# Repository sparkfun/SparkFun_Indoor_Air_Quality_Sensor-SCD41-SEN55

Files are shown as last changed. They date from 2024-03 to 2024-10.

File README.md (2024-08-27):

SparkFun Indoor Air Quality Sensor - SCD41 SEN55 (Qwiic)
========================================

SparkFun Indoor Air Quality Sensor - SCD41 SEN55 (https://www.sparkfun.com/products/25200)

[*SparkFun Indoor Air Quality Sensor - SCD41 SEN55 (SEN-25200)*](https://www.sparkfun.com/products/25200)

The SparkFun Indoor Air Quality Sensor - SCD41 SEN55 (Qwiic) combines two excellent indoor air quality sensors in the SCD41 and SEN55 from Sensirion<sup>&trade;</sup> to provide a comprehensive indoor air quality sensor that measures CO<sub>2</sub>, Volatile Organic Compounds (VOCs), particulate matter (PM1.0, 2.5, 4, and 10) along with temperature and relative humidity. The board includes a pair of Qwiic connectors as well as a 0.1"-spaced through-hole header for I<sup>2</sup>C connections as well as power inputs.

Repository Contents
-------------------

* **/docs** - Markdown files for Hookup Guide
* **/Documents** - Datasheets, additional product information
* **/Firmware** - Example code 
* **/Hardware** - Eagle design files (.brd, .sch)

Documentation
--------------
* **[SparkFun SCD4x Library](https://github.com/sparkfun/SparkFun_SCD4x_Arduino_Library)** - Arduino library for SDC4x sensor boards.
* **[Sensirion Arduino Core Library](https://github.com/Sensirion/arduino-core)** - Arduino core library for Sensirion sensors.
* **[Sensirion SEN5x Library](https://github.com/Sensirion/arduino-i2c-sen5x)** - Arduino library for the Sensirion SEN55.
* **[Hookup Guide](https://sparkfun.github.io/SparkFun_Indoor_Air_Quality_Sensor-SCD41-SEN55)** - Basic hookup guide for the SparkFun Indoor Air Quality Sensor - SCD41 SEN55 (Qwiic).

Product Versions
----------------
* [SEN-25200](https://www.sparkfun.com/products/25200) - Initial product release.

License Information
-------------------

This product is _**open source**_! 

Please review the LICENSE.md file for license information. 

If you have any questions or concerns on licensing, please contact technical support on our [SparkFun forums](https://forum.sparkfun.com/viewforum.php?f=152).

Distributed as-is; no warranty is given.

- Your friends at SparkFun.

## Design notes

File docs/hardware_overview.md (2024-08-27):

---
icon: material/cog
---

Let's take a closer look at the pair of sensors along with other hardware present on this Qwiic sensor breakout.

## SEN55 Particle, VOC, Humidity, and Temperature Sensor

The SEN55 Particle and VOC sensor module measures particulate matter and volatile organic compounds (VOCs) along with humidity and temperature. The SEN55 is designed with the idea to be a simple plug-and-play solution and includes all sensors, processors, power control, and fan inside a compact housing all with a single, calibrated, digital signal output communicating over I<sup>2</sup>C making it perfect to integrate into this Qwiic combination breakout.

<figure markdown>
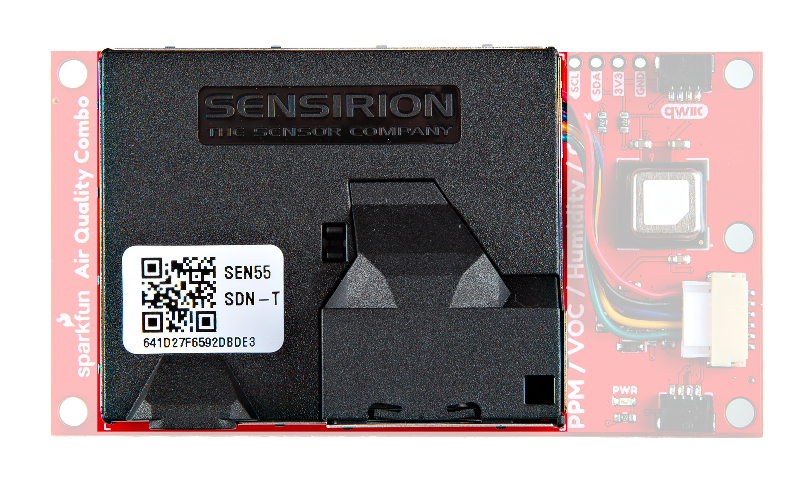
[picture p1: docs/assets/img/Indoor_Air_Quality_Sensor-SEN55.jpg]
Photo highlighting SEN55

</figure>

The SEN55 reports measurments of particulate matter, VOC index, NO<sub>x</sub> indect, temperature, and relative humidity every second. The sensor measures particulates of the following size specifications: PM1, PM2.5, PM4, and PM10 from a concentration of 0 to 1,000 &micro;g/m<sup>3</sup>. It also senses both VOC and NO<sup>x</sup> indexes from 1 to 500 index points. Lastly, it measures temperature from 15 to 30&deg;C and relative humidity from 30 to 70%RH. It offers a robust set of control registers to take and report measurements as well as check the status of the module and its components. The table below outlines some of the sensing parameters for the SEN55. Refer to the [datasheet](./assets/component_documentation/Sensirion_Datasheet_Environmental_Node_SEN5x.pdf) for a complete overview.

<table>
    <tr>
        <th>Parameter</th>
        <th>Units</th>
        <th>Min</th>
        <th>Typ</th>
        <th>Max</th>
        <th>Conditions/Notes</th>
    </tr>
    <tr>
        <td>Mass concentration range</td>
        <td>&micro;g/m<sup>3</sup></td>
        <td>-</td>
        <td>0</td>
        <td>-</td>
        <td>1,000</td>
        <td>-</td>        
    </tr>
    <tr>
        <td>PM1.0 Mass concentration size</td>
        <td>&micro;g</td>
        <td>0.3</td>
        <td>-</td>
        <td>1.0</td>
        <td>-</td>
    </tr>
    <tr>
        <td>PM2.5 Mass concentration size</td>
        <td>&micro;g</td>
        <td>0.3</td>
        <td>-</td>
        <td>2.5</td>
        <td>-</td>
    </tr>
    <tr>
        <td>PM4 Mass concentration size</td>
        <td>&micro;g</td>
        <td>0.3</td>
        <td>-</td>
        <td>4.0</td>
        <td>-</td>
    </tr>
    <tr>
        <td>PM10 Mass concentration size</td>
        <td>&micro;g</td>
        <td>0.3</td>
        <td>-</td>
        <td>10.0</td>
        <td>-</td>
    </tr>
    <tr>
        <td>Temperature accuracy (Typ.)</td>
        <td>&deg;C</td>
        <td>-</td>
        <td>&plusmn;0.45</td>
        <td>-</td>
        <td>@ 15-30 &deg;C, 50 %RH</td>
    </tr>
    <tr>
        <td>Temperature repeatability</td>
        <td>&deg;C</td>
        <td>-</td>
        <td>0.1</td>
        <td>-</td>
        <td>@25&deg;C, 50 %RH</td>
    </tr>
    <tr>
        <td>Relative humidity accuracy (Typ.)</td>
        <td>%RH</td>
        <td>-</td>
        <td>&plusmn;4.5</td>
        <td>-</td>
        <td>@25&deg;C, 30-70 %RH</td>
    </tr>
    <tr>
        <td>Relative humidity repeatability</td>
        <td>%RH</td>
        <td>-</td>
        <td>&plusmn;1</td>
        <td>-</td>
        <td>@25&deg;C, 50 %RH</td>
    </tr>
    <tr>
        <td>VOC Index output</td>
        <td>VOC Index points</td>
        <td>1</td>
        <td>-</td>
        <td>500</td>
        <td>-</td>
    </tr>
    <tr>
        <td>VOC Index repeatability</td>
        <td>VOC Index points</td>
        <td>-</td>
        <td><&plusmn;5</td>
        <td>-</td>
        <td>-</td>
    </tr>
    <tr>
        <td>NO<sub>x</sub> Index output</td>
        <td>NO<sub>x</sub> Index points</td>
        <td>1</td>
        <td>-</td>
        <td>500</td>
        <td>-</td>
    </tr>
    <tr>
        <td>NO<sub>x</sub> Index repeatability</td>
        <td>NO<sub>x</sub> Index points</td>
        <td>-</td>
        <td><&plusmn;10</td>
        <td>-</td>
        <td>-</td>
    </tr>
</table>

### SEN55 Power

The SEN55 accepts a supply voltage between <b>4.5V</b> to <b>5.5V</b> with a typical voltage of <b>5V</b> with a peak current draw of <b>110mA@5V</b>. The SparkFun Indoor Air Quality Sensor uses an on-board buck/boost circuit to boost the <b>3.3V</b> from a Qwiic connector or to the <b>3.3V</b> PTH pin to <b>5V</b>.

## SCD41 CO<sub>2</sub> Humidity and Temperature Sensor

The SCD41 CO<sub>2</sub> sensor uses Sensirion's PASense<sup>&trade;</sup>, a photoacoustic measurement system, to accurately measure CO<sub>2</sub> concentration using a combination of a narrow band of IR light and a microphone. The sensor also has a built-in humidity and temperatuer sensor using Sensirion's CMOSens<sup>&trade;</sup> technology to provide environmental data and compensate for environmental conditions in CO<sub>2</sub> measurement. For a detailed overview of the SCD41 sensor, refer to the [datasheet](./assets/component_documentation/Sensirion_CO2_Sensors_SCD4x_Datasheet.pdf).

<figure markdown>
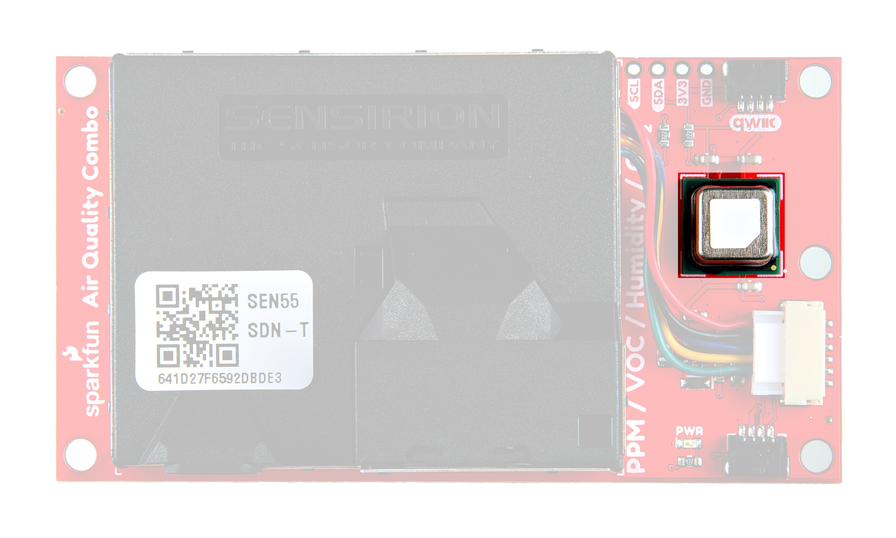
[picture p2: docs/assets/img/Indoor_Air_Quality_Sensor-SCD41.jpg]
Photo highlighting SCD41

</figure>

Now you may be curious as to just what photoacoustic measuring actually is. Photoacoustic measuring uses light (photo) and sound/vibrations (acoustic) in tandem to measure the the photoacoustic effect when energy is absorbed by particles (in the case of these sensors, CO<sub>2</sub> molecules). The SCD41 has an IR emitter with a filter to shine a specific IR light into the sensing area. CO<sub>2</sub> molecules inside the sensing area absorb energy from the emitted IR light and vibrate. The microphone inside the sensing area picks up this acoustic vibration and then this data is processed to report CO<sub>2</sub> concentration. This is just a quick and basic explanation of the photoacoustic process used in this sensor. For detailed information on Sensirion's PASens and CMOSens technology, refer to their [technology page](https://sensirion.com/products/technology).

<table>
    <tr>
        <th>Parameter</th>
        <th>Units</th>
        <th>Min</th>
        <th>Typ</th>
        <th>Max</th>
        <th>Notes</th>
    </tr>
    <tr>
        <td>CO<sub>2</sub> Output Range</td>
        <td>ppm</td>
        <td>0</td>
        <td>-</td>
        <td>40,000</td>
        <td></td>
    </tr>
    <tr>
        <td>CO<sub>2</sub> Measurement Accuracy</td>
        <td>ppm</td>
        <td>-</td>
        <td>&plusmn;(40 + 5%)</td>
        <td>-</td>
        <td>-</td>
    </tr>
    <tr>
        <td>Humidity Range</td>
        <td>%RH</td>
        <td>0</td>
        <td>-</td>
        <td>100</td>
        <td></td>
    </tr>
    <tr>
        <td rowspan="2" style="vertical align middle">Humidity Accuracy</td>
        <td rowspan="2" style="vertical align middle">%RH</td>
        <td>-</td>
        <td>&plusmn;6</td>
        <td>-</td>
        <td>15&deg;C - 35&deg;C, 20%RH - 65%RH</td>
    </tr>
    <tr>
        <td>-</td>
        <td>&plusmn;9</td>
        <td>-</td>
        <td>-10&deg;C - 60 &deg;C, 0%RH - 100%RH</td>
    </tr>
    <tr>
        <td>Temperature Range</td>
        <td>&deg;C</td>
        <td>-10</td>
        <td>-</td>
        <td>60</td>
        <td></td>
    </tr>
    <tr>
        <td rowspan="2" style="vertical align middle">Temperature Accuracy</td>
        <td rowspan="2" style="vertical align middle">&deg;C</td>
        <td>-</td>
        <td>&plusmn;0.8</td>
        <td>-</td>
        <td>15&deg;C - 35&deg;C</td>
    </tr>
    <tr>
        <td>-</td>
        <td>&plusmn;1.5</td>
        <td>-</td>
        <td>-10&deg;C - 60&deg;C</td>
    </tr>
</table>

## Qwiic & I<sup>2</sup>C Interface

The Indoor Air Quality Sensor operates over I<sup>2</sup>C using either the two Qwiic connectors or the 0.1"-spaced plated through-hole (PTH) header. Power for the board is supplied over either of these options as well.

<figure markdown>
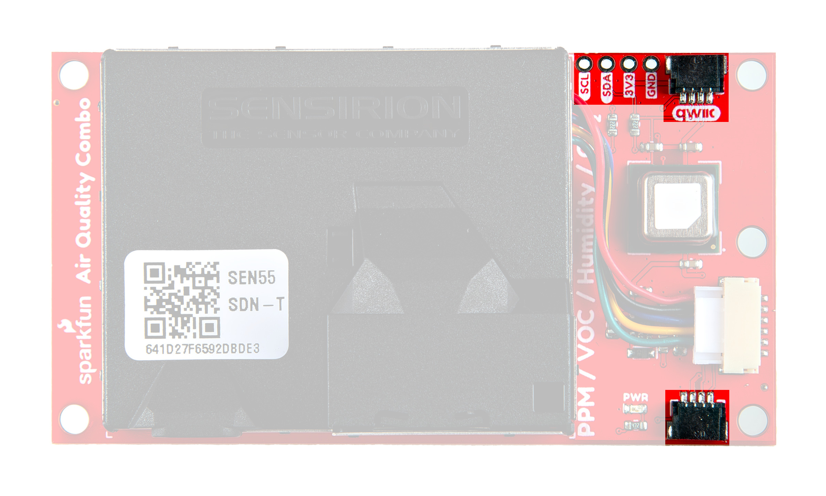
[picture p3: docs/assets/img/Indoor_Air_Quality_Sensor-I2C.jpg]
Photo highlighting Qwiic connectors & I2C header.

</figure>

## Power LED

There is just one red LED on the board to indicate power. By default, it is always powered whenever <b>3.3V</b> is present though users can disable it by adjusting the solder jumper covered in the next section.

<figure markdown>
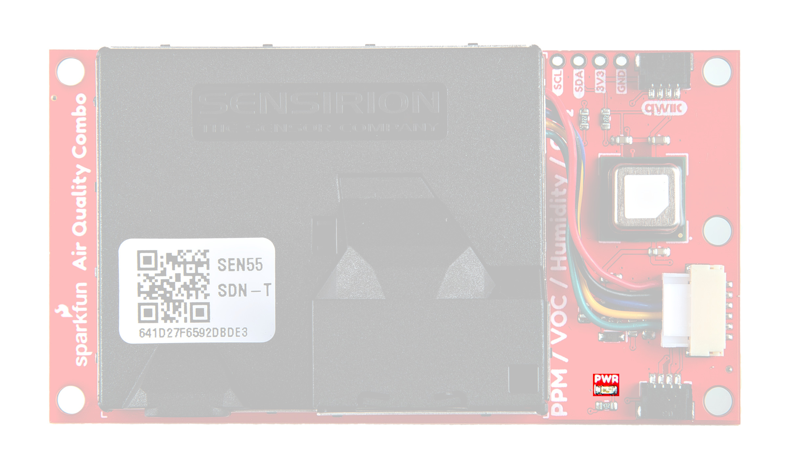
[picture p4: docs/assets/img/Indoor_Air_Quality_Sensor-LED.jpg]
Photo highlighting Power LED.

</figure>

## Solder Jumpers

The board has two solder jumpers labeled <b>PWR</b> and <b>I2C</b>. The <b>PWR</b> jumper completes the power LED circuit and is CLOSED by default. Open the jumper to disable the power LED. The <b>I2C</b> jumper pulls the I<sup>2</sup>C SDA and SCL lines to <b>3.3V</b> via a pair of <b>2.2k</b>&ohm; resistors. This three way jumper is completely closed by default. Open it completely to disable the pullup resistors.

<figure markdown>
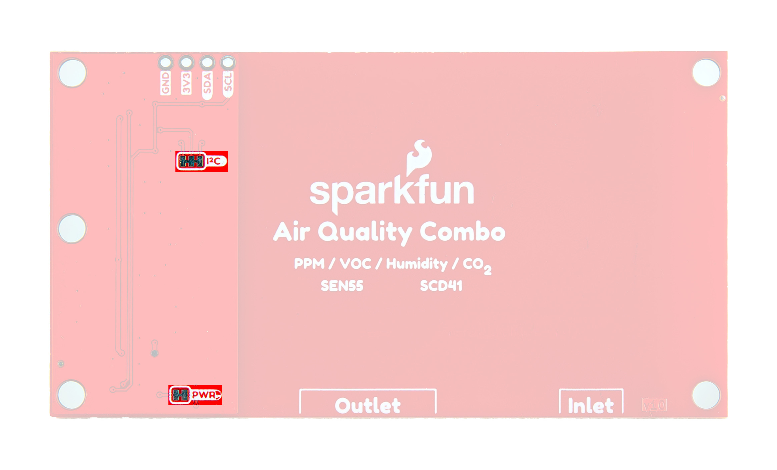
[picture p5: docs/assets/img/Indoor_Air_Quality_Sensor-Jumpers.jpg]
Photo highlighting solder jumpers.

</figure>

## Board Dimensions

This Qwiic breakout runs a bit larger than standard Qwiic breakouts to fit the SEN55 and measures 3.25" x 1.75" (82.55mm x 44.45mm) and has four mounting holes that fit a [4-40 screw](https://www.sparkfun.com/products/10453). The SEN55 is a bit of an odd shape to fit everything in the housing but it measures 0.878" (22.3mm) at it's tallest and it's footprint is 2.06" x  1.70" (52.3 mm x 43.3 mm). For detailed measurements of the entire sensor package, refer to the [SEN55 datasheet](./assets/component_documentation/Sensirion_Datasheet_Environmental_Node_SEN5x.pdf).

<figure markdown>
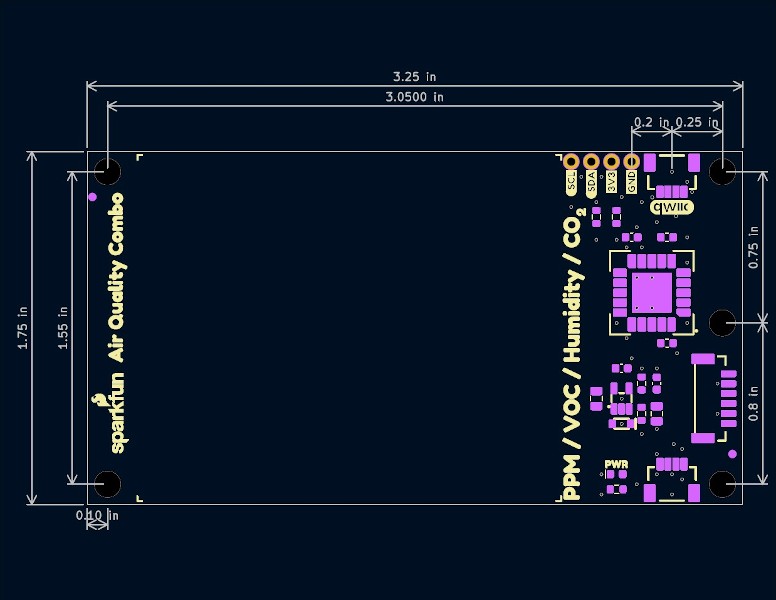
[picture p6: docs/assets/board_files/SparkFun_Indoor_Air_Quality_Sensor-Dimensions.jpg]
Board dimensions

</figure markdown>

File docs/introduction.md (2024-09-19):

---
icon: material/book-open-page-variant
---

<div class="grid cards desc" markdown>

-    <a href="https://www.sparkfun.com/products/25200">
    **SparkFun Indoor Air Quality Combo Sensor - SCD41, SEN55 (Qwiic)**<br>
    **SKU:** SEN-25200

    ---

    <figre markdown>
    Product Thumbnail
    </figure></a>

    <center>
    <article class="video_desc">
    <iframe src="https://www.youtube.com/embed/Cn1trZE5GPI?si=KZZngeRyTVlIOeQ6" title="Product Showcase: SparkFun Indoor Air Quality Combo Sensor - SCD41, SEN55 (Qwiic)" frameborder="0" allow="accelerometer; autoplay; clipboard-write;encrypted-media; gyroscope; picture-in-picture" allowfullscreen></iframe>
    </article>
    </center>

-    The SparkFun Indoor Air Quality Combo Sensor - SCD41 SEN55 (Qwiic) combines two excellent indoor air quality sensors in the SCD41 and SEN55 from Sensirion<sup>&trade;</sup> to provide a comprehensive indoor air quality sensor that measures CO<sub>2</sub>, Volatile Organic Compounds (VOCs), particulate matter (PM1.0, 2.5, 4, and 10) along with temperature and relative humidity.<br>
The SparkFun Qwiic Indoor Air Quality Combo Sensor takes care of all the power requirements of the SEN55 and SCD41 with onboard DC voltage conversion, allowing a simple, single Qwiic connection for power and communication.

    <center>
    [Purchase from SparkFun :fontawesome-solid-cart-plus:{ .heart }](https://www.sparkfun.com/products/25200){ .md-button .md-button--primary }
    </center>

</div>

## Required Materials

To follow along with this guide you will need a microcontroller to communicate with the Indoor Air Quality Combo Board. Below are a few options that come Qwiic-enabled out of the box:

<div class="grid cards" markdown>

-   <a href="https://www.sparkfun.com/products/20168">

    <figure markdown>
    SparkFun Thing Plus - ESP32 WROOM (USB-C)
    </figure>
    </a>
    ---
    <a href="https://www.sparkfun.com/products/20168">
    **SparkFun Thing Plus - ESP32 WROOM (USB-C)**<br>
    DEV-20168
    </a>

-   <a href="https://www.sparkfun.com/products/22925">

    <figure markdown>
    SparkFun Qwiic Pocket Development Board - ESP32-C6
    </figure>
    </a>
    ---
    <a href="https://www.sparkfun.com/products/22925">**SparkFun Qwiic Pocket Development Board - ESP32-C6**<br>
    DEV-22925
    </a>

-   <a href="https://www.sparkfun.com/products/15574">
    
    <figure markdown>
    SparkFun Thing Plus - Artemis
    </figure>
    </a>
    ---
    <a href="https://www.sparkfun.com/products/15574">
    **SparkFun Thing Plus - Artemis**<br>
    DEV-18158
    </a>

-   <a href="https://www.sparkfun.com/products/18158">
    
    <figure markdown>
    SparkFun RedBoard Plus
    </figure>
    </a>
    ---
    <a href="https://www.sparkfun.com/products/18158">
    **SparkFun RedBoard Plus**<br>
    DEV-18158
    </a>

</div>

If your chosen microcontroller is not already Qwiic-enabled, you can add that functionality with one or more of the following items:

<div class="grid cards" markdown>

-   <a href="https://www.sparkfun.com/products/15081">

    <figure markdown>
    SparkFun Qwiic Cable Kit
    </figure>
    </a>
    ---
    <a href="https://www.sparkfun.com/products/15081">
    **SparkFun Qwiic Cable Kit**<br>
    KIT-15081
    </a>

-   <a href="https://www.sparkfun.com/products/14495">
    
    <figure markdown>
    SparkFun Qwiic Adapter
    </figure>
    </a>
    ---
    <a href="https://www.sparkfun.com/products/14495">
    **SparkFun Qwiic Adapter**<br>
    DEV-14495
    </a>

-   <a href="https://www.sparkfun.com/products/14352">
    
    <figure markdown>
    SparkFun Qwiic Shield for Arduino
    </figure>
    </a>
    ---
    <a href="https://www.sparkfun.com/products/14352">
    **SparkFun Qwiic Shield for Arduino**<br>
    DEV-14352
    </a>

-   <a href="https://www.sparkfun.com/products/16790">

    <figure markdown>
    SparkFun Qwiic Shield for Thing Plus
    </figure>
    </a>
    ---
    <a href="https://www.sparkfun.com/products/16790">
    **SparkFun Qwiic Shield for Thing Plus**<br>
    DEV-16790
    </a>
</div>

You will also need at least one Qwiic cable to connect the air quality sensor board to your microcontroller:

<div class="grid cards" markdown>

-   <a href="https://www.sparkfun.com/products/17259">

    <figure markdown>
    Flexible Qwiic Cable - 100mm)
    </figure>
    </a>
    ---
    <a href="https://www.sparkfun.com/products/17259">
    **Flexible Qwiic Cable - 100mm**<br>
    PRT-17259
    </a>

-   <a href="https://www.sparkfun.com/products/17260">
    
    <figure markdown>
    Qwiic Cable - 50mm
    </figure>
    </a>
    ---
    <a href="https://www.sparkfun.com/products/17260">
    **Flexible Qwiic Cable - 50mm**<br>
    PRT-17260
    </a>

-   <a href="https://www.sparkfun.com/products/17257">
    
    <figure markdown>
    Flexible Qwiic Cable - 500mm
    </figure>
    </a>
    ---
    <a href="https://www.sparkfun.com/products/17257">
    **Flexible Qwiic Cable - 500mm**<br>
    PRT-17257
    </a>

-   <a href="https://www.sparkfun.com/products/17261">

    <figure markdown>
    Flexible Qwiic Cable - Female Jumper (4-pin)
    </figure>
    </a>
    ---
    <a href="https://www.sparkfun.com/products/17261">**Flexible Qwiic Cable - Female Jumper (4-pin)**<br>
    CAB-17261
    </a>
</div>

## Optional Materials

If you prefer a soldered connection or want to modify the solder jumpers on this board, you may need some of the products listed below:

<div class="grid cards" markdown align="center">

-   <a href="https://www.sparkfun.com/products/24063">
    
    <figure markdown>
    PINECIL Soldering Iron Kit
    </figure>
    </a>
    ---
    <a href="https://www.sparkfun.com/products/24063">
    **PINECIL Soldering Iron Kit**<br>
    TOL-24063
    </a>

-   <a href="https://www.sparkfun.com/products/116">

    <figure markdown>
    Break Away Headers - Straight)
    </figure>
    </a>
    ---
    <a href="https://www.sparkfun.com/products/116">
    **Break Away Headers - Straight**<br>
    PRT-00116
    </a>

-   <a href="https://www.sparkfun.com/products/9200">
    
    <figure markdown>
    Hobby Knife
    </figure>
    </a>
    ---
    <a href="https://www.sparkfun.com/products/9200">
    **Hobby Knife**<br>
    TOL-09200
    </a>

-   <a href="https://www.sparkfun.com/products/14579">

    <figure markdown>
    Chip Quik No-Clean Flux Pen - 10mL
    </figure>
    </a>
    ---
    <a href="https://www.sparkfun.com/products/14579">**Chip Quik No-Clean Flux Pen - 10mL**<br>
    CAB-14579
    </a>
</div>

## Suggested Reading

We designed this board for easy integration into SparkFun's Qwiic connect system.  Click on the banner below to learn more about the [SparkFun Qwiic Connect System](https://www.sparkfun.com/qwiic).

<div style="text-align: center">
<table>
  <tr>
   <td>
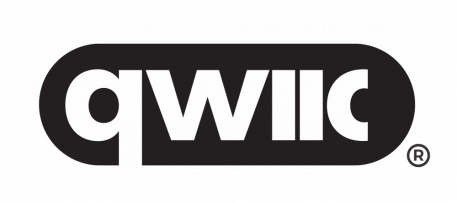
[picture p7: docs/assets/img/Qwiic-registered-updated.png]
Qwiic Connect System Click to learn more about the Qwiic Connect System!
   <div style="text-align: center"></div>
   </td>
  </tr>
  <tr>
    <td><div style="text-align: center"><i><a href="https://www.sparkfun.com/qwiic">Qwiic Connect System</a></i></div></td>
  </tr>
</table>
</div>

Before getting started with this Hookup Guide, you may want to read through the tutorials below if you are not familiar with the concepts covered in them or want a refresher. If you are using either of the Qwiic Shields linked above, we recommend reading through their respective Hookup Guides before continuing with this tutorial:

<div class="grid cards hide col-4" markdown align="center">

-   <a href="https://learn.sparkfun.com/tutorials/8">
    <figure markdown>
    Serial Communication
    </figure>
    </a>
    <a href="https://learn.sparkfun.com/tutorials/8">**Serial Communication**
    </a>

-   <a href="https://learn.sparkfun.com/tutorials/82">
    <figure markdown>
    I2C
    </figure>
    </a>
    <a href="https://learn.sparkfun.com/tutorials/82">**I2C**
    </a>

-   <a href="https://learn.sparkfun.com/tutorials/62">
    <figure markdown>
    Logic Levels
    </figure>
    </a>
    <a href="https://learn.sparkfun.com/tutorials/62">**Logic Levels**
    </a>

-   <a href="https://learn.sparkfun.com/tutorials/61">
    <figure markdown>
    Installing Arduino IDE
    </figure>
    </a>
    <a href="https://learn.sparkfun.com/tutorials/61">**Installing Arduino IDE**
    </a>

-   <a href="https://learn.sparkfun.com/tutorials/15">
    <figure markdown>
    Installing an Arduino Library
    </figure>
    </a>
    <a href="https://learn.sparkfun.com/tutorials/15">**Installing an Arduino Library**
    </a>

-   <a href="https://learn.sparkfun.com/tutorials/112">
    <figure markdown>
    Serial Terminal Basics
    </figure>
    </a>
    <a href="https://learn.sparkfun.com/tutorials/112">**Serial Terminal Basics**
    </a>

-   <a href="https://learn.sparkfun.com/tutorials/664">
    <figure markdown>
    How to Work with Jumper Pads and PCB Traces
    </figure>
    </a>
    <a href="https://learn.sparkfun.com/tutorials/664">**How to Work with Jumper Pads and PCB Traces**
    </a>

-   <a href="https://learn.sparkfun.com/tutorials/684">
    <figure markdown>
    Qwiic Shield for Arduino & Photon Hookup Guide
    </figure>
    </a>
    <a href="https://learn.sparkfun.com/tutorials/684">**Qwiic Shield for Arduino & Photon Hookup Guide**
    </a>

-   <a href="https://learn.sparkfun.com/tutorials/1107">
    <figure markdown>
    Qwiic Shield for Thing Plus Hookup Guide
    </figure>
    </a>
    <a href="https://learn.sparkfun.com/tutorials/1107">**Qwiic Shield for Thing Plus Hookup Guide**
    </a>
</div>

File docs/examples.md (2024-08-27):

---
icon: simple/arduino
---

We've included a couple basic examples to get up and running with the Indoor Air Quality Sensor in the GitHub repository. You can either download a copy of the [GitHub Repo](https://github.com/sparkfun/SparkFun_Indoor_Air_Quality_Sensor-SCD41-SEN55) or get a compressed .ZIP of the repo by clicking the button below. Alternatively, you can copy the code block in the following section into a blank Arduino sketch.

<center>
    [SparkFun Indoor Air Quality Sensor - SCD41 SEN55 GitHub Repository (ZIP)](https://github.com/sparkfun/SparkFun_Indoor_Air_Quality_Sensor-SCD41-SEN55/archive/refs/heads/main.zip){ .md-button .md-button--primary }
</center>

## Example 1 - Combined Readings

The first example demonstrates how to output basic readings from both the SEN55 and SCD41 over serial. The code initializes both 

<figure markdown>
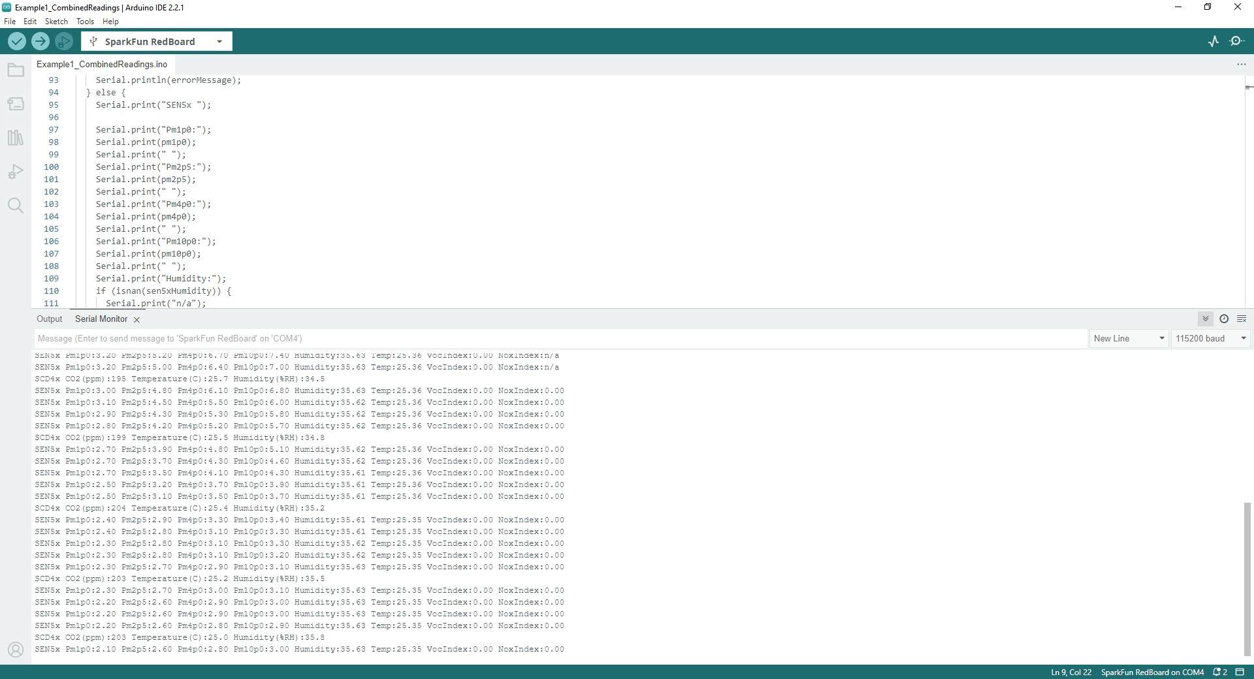
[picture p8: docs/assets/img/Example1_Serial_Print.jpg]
Screenshot of serial printout of Example 1 - Combined Readings

</figure>

Since the SCD41 only reports data every five seconds, you'll see four readings from the SEN55 for every one reading from the SCD41.

### Code to Note

Both the SCD41 and SEN55 have default temperature compensation for internal heating in the devices but if the Indoor Air Quality is designed into another device, you may need to adjust the temperature compensation for heat generated by other devices in the vicinity. For detailed instructions on achieving optimal performance from the SEN55, refer to the app note titled "Temperature Acceleration and Compensation Instructions for SEN5x" on Sensirion's [SEN55 product page](https://sensirion.com/products/catalog/SEN55). We highly recommend referring to this document for further information on the advanced compensation settings used in the `setTemperatureOffsetParameters`, `setWarmStartParameter`, and `setRhtAccelerationMode` functions.

## Example 2 - Module Version

The second example is nearly identical to the first but it also includes a printout of the serial number and module version at the start then proceeds to report air quality data from both sensors. These values are stored in an I<sup>2</sup>C buffer that uses up to 48 bytes so it may not work for all Arduino microcontrollers. The serial number and module version are printed out

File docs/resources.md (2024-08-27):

For more information about the SparkFun Indoor Air Quality Sensor - SCD41, SEN55 (Qwiic), take a look at the resources and documentation below:

* [Schematic](./assets/board_files/SparkFun_Indoor_Air_Quality_Sensor-Schematic.pdf)
* [KiCad Files](./assets/board_files/SparkFun%20Indoor%20Air%20Quality%20Sensor%20-%20SCD41%20SEN55.zip)
* [Board Dimensions](./assets/board_files/SparkFun_Indoor_Air_Quality_Sensor-Dimensions.pdf)
* [GitHub Hardware Repo](https://github.com/sparkfun/SparkFun_Indoor_Air_Quality_Sensor-SCD41-SEN55)
* [SEN55 Datasheet](./assets/component_documentation/Sensirion_Datasheet_Environmental_Node_SEN5x.pdf)
* [SCD4x Datasheet](./assets/component_documentation/Sensirion_SCD4x_Datasheet.pdf)
* [SparkFun SCD4x Arduino Library](https://github.com/sparkfun/SparkFun_SCD4x_Arduino_Library)
* [Sensirion Arduino Core Library](https://github.com/Sensirion/arduino-core)
* [Sensirion SEN5x Arduino Library](https://github.com/Sensirion/arduino-i2c-sen5x)
* [Qwiic Resource Page](https://www.sparkfun.com/qwiic)

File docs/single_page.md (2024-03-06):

---
hide:
  - navigation
  - toc
icon: fontawesome/solid/scroll
---

# Introduction
--8<-- "./docs/introduction.md:5"

# Hardware Overview
--8<-- "./docs/hardware_overview.md:5"

# Hardware Assembly
--8<-- "./docs/hardware_assembly.md:5"

# Software Setup
--8<-- "./docs/software_setup.md:5"

# Example Code
--8<-- "./docs/examples.md"

# Troubleshooting Tips
--8<-- "./docs/troubleshooting.md"

# Resources:
--8<-- "./docs/resources_and_going_further.md"

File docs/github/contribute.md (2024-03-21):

# Help Improve the Experience!
Spot an improvement opportunity? Feel free to contribute to our open-source design and documentation. 

## Enhance our Documentation
All of this documentation can be modified by you! Please help us make it better.

* These pages are contained in the [`docs` folder](https://github.com/sparkfun/SparkFun_Indoor_Air_Quality_Sensor-SCD41-SEN55/tree/main/docs) of the [SparkFun SparkFun Air Quality Combo](https://github.com/sparkfun/SparkFun_Indoor_Air_Quality_Sensor-SCD41-SEN55) repository.

### Submit a Correction
1. Fork this repo
2. Add your corrections or improvements to the markdown file
3. File a pull request with your changes, and enjoy making the ~~words~~ ~~worlds~~ world a better place.
	* Once received, the documentation specialist will automatically be notified.
	* We will review your suggested improvements to make sure they are correct and fit within our documentation standards.

## Upgrade our Hardware Design
All of our designs are open-source! Please help us make it better.

* Our board design files are contained in the [`Hardware` folder](https://github.com/sparkfun/SparkFun_Indoor_Air_Quality_Sensor-SCD41-SEN55/tree/main/Hardware) of the [SparkFun SparkFun Air Quality Combo](https://github.com/sparkfun/SparkFun_Indoor_Air_Quality_Sensor-SCD41-SEN55) repository.

### Submit a Design Improvement
1. Fork this repo
2. Add your design modifications
3. File a pull request with your changes, and enjoy making the world a better place.
	* Once received, the engineer in charge of the original design will automatically be notified.
	* We will review your suggested upgrades, if they are within our board design standards and meet our product design requirements, we will flag these changes for our next board revision.
	
	!!! note
		Please note, that even if your suggestion is accepted, these changes may not be immediate. We may have to cycle through our current product inventory first.

## Contributors
Let's provide some recognition to those who have contributed to this project!

GitHub Contributors Image
<br>


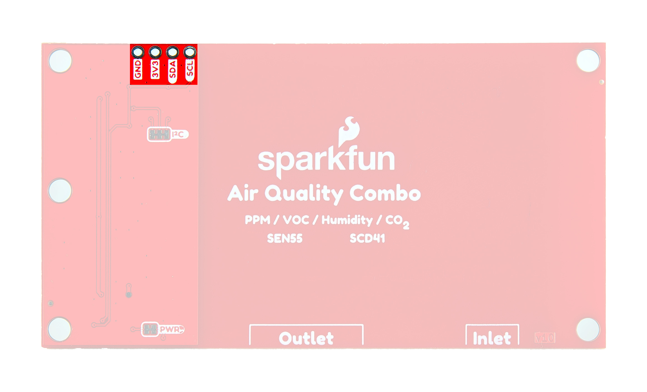
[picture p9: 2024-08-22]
docs/assets/img/Indoor_Air_Quality_Sensor-PTH_Back.jpg

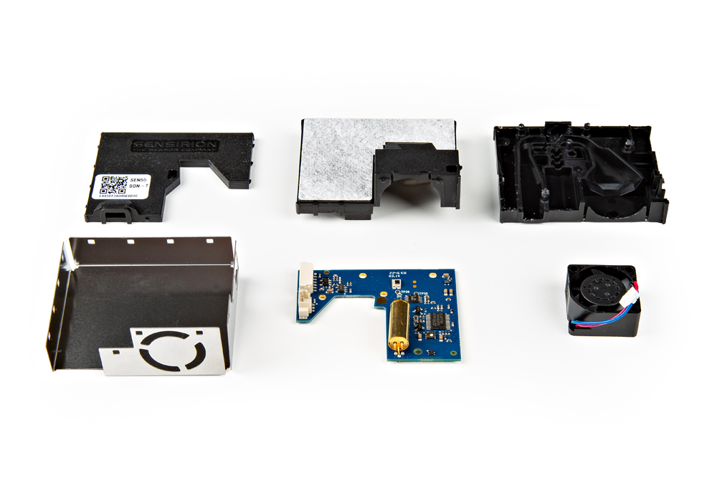
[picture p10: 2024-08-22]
docs/assets/img/Indoor-Air-Quality-Sensor-SEN55_2.jpg

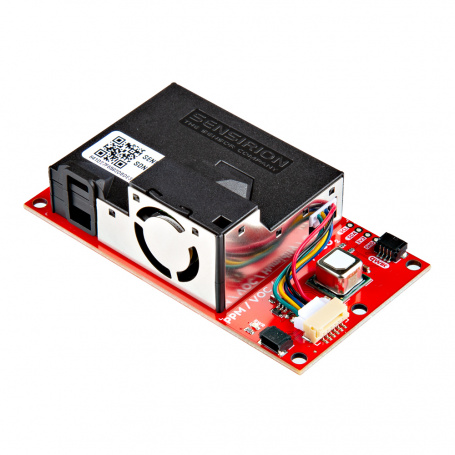
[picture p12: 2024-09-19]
docs/assets/img/Indoor_Air_Quality_Sensor-Feature.jpg

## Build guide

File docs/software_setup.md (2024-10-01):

---
icon: simple/arduino
---

!!! attention
	If this is your first time using Arduino, please read through our tutorial on [installing the Arduino IDE](https://learn.sparkfun.com/tutorials/installing-arduino-ide). If you have not installed an Arduino library before, we recommend you check out our [installation guide](https://learn.sparkfun.com/tutorials/installing-an-arduino-library).

We've written a couple examples to demonstrate the basics and configuration options for the Indoor Air Quality Sensor SCD41 SEN55 built using a couple of Sensirion's Arduino libraries for these sensors along with SparkFun's SCD4x library. Users can install these libraries through the Arduino Library Manager tool by searching for <b>"Sensirion Core"</b>, <b>"Sensirion I2C SEN5x"</b>, and <b>"SparkFun SCD4x</b> then install the latest version.

Those who prefer to manually install the libraries can download ZIPs of the libraries by clicking the buttons below:

<center>
[SparkFun SCD4x Arduino Library (ZIP)](https://github.com/sparkfun/SparkFun_SCD4x_Arduino_Library/archive/refs/heads/main.zip){ .md-button .md-button--primary }
</center>

<center>
[Sensirion Arduino Core Library (ZIP)](https://github.com/Sensirion/arduino-core/archive/refs/heads/main.zip){ .md-button .md-button--primary }
</center>

<center>
[Sensirion I2C SEN5x Arduino Library (ZIP)](https://github.com/Sensirion/arduino-i2c-sen5x/archive/refs/heads/master.zip){ .md-button .md-button--primary}
</center>

With the libraries installed let's move on to looking at a few of the examples included in it.

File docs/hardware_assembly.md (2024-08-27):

---
icon: material/tools
---

Now that we're familiar with the SEN55 and SCD41 on this breakout, it's time to assemble it into a circuit.

## Qwiic Assembly

SparkFun's Qwiic system makes assembling a circuit a breeze. Simply plug the breakout into your chosen microcontroller with a Qwiic cable. After assembling your circuit, it should look similar to the photo below:

<figure markdown>
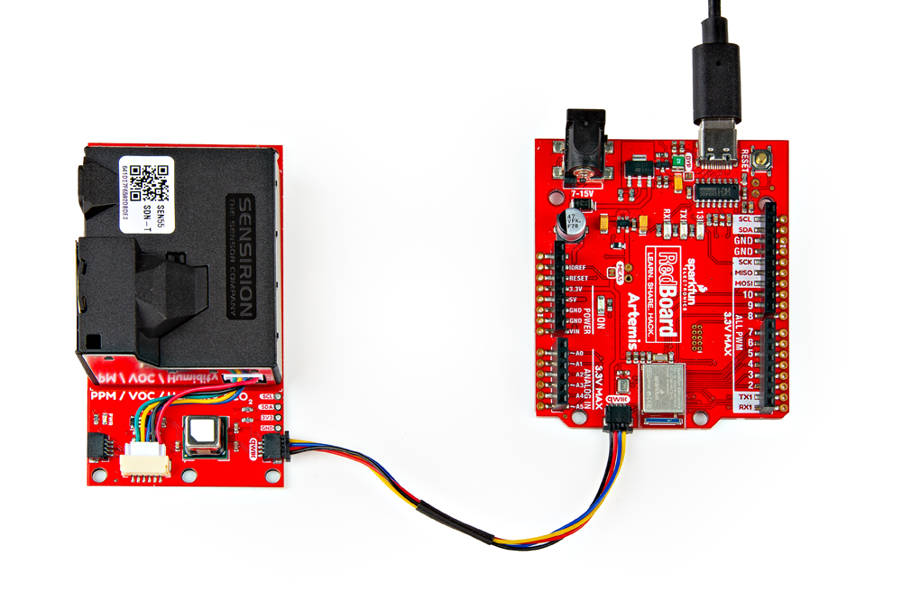
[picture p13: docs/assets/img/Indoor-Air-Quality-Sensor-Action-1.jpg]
Photo of completed Qwiic assembly.

</figure>

Reminder, for ideal results, make sure to fully calibrate the SCD41 by taking continuous measurements for one hour every day for seven days.

## Soldered Assembly

Those who prefer a traditional soldered assembly should solder wires or header pins to the PTH header on the side of the board. If you're not familiar with through-hole soldering or would like a refresher, take a look at our Through-Hole Soldering Tutorial:

<div class="grid cards" markdown align="center">

-   <a href="https://learn.sparkfun.com/tutorials/5">
    <figure markdown>
    How to Solder: Through-Hole Soldering
    </figure>
    </a>
    <a href="https://learn.sparkfun.com/tutorials/5">**How to Solder: Through-Hole Soldering**
    </a>

</div>

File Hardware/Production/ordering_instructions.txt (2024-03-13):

Ordering Instructions:
Panel dimensions: 179.30 x 148.05 mm.
Material: TG155
Solder Mask: Red
Silkscreen: White
Layers: 2
Finish: Lead-Free HASL
Thickness: 1.6mm
Outer Copper Weight: 1oz
Minimum track width: 0.18mm (7.00mil)
Minimum via drill: 0.30mm (11.81mil)

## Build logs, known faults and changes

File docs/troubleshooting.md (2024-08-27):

## SCD41 Calibration Period

Reminder, for best results, Sensirion recommends taking continuous readings for at least one hour a day of 'fresh air' for the calibration period to complete.

## General Troubleshooting

!!! warning "Need Help?"
    If you need technical assistance or more information on a product that is not working as you expected, we recommend heading on over to the [SparkFun Technical Assistance](https://www.sparkfun.com/technical_assistance) page for some initial troubleshooting.

    <center>
    [SparkFun Technical Assistance Page](https://www.sparkfun.com/technical_assistance){ .md-button .md-button--primary }
    </center>
    
    If you can't find what you need there, the [SparkFun Forums](https://community.sparkfun.com/) is a great place to search product forums and ask questions.
    
    !!! info "Account Registration Required"
        If this is your first visit to our forum, you'll need to create a Forum Account by clicking the "Sign Up" button in the top right to post questions.

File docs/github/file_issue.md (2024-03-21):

# Did we make a mistake?

Spot something wrong? Please let us know. 

!!! attention
	This is not where customers should seek assistance on a product. If you require technical assistance or have questions about a product that is not working as expected, please head over to the [SparkFun Technical Assistance](https://www.sparkfun.com/technical_assistance) page for some initial troubleshooting.
    <center>
    [SparkFun Technical Assistance Page](https://www.sparkfun.com/technical_assistance){ .md-button .md-button--primary }
    </center>
    
    If you can't find what you need there, the [SparkFun Forums](https://forum.sparkfun.com/index.php) is a great place to search product forums and ask questions.
    
    !!! info "Account Registration Required"
        If this is your first visit to our forum, you'll need to create a [Forum Account](https://forum.sparkfun.com/ucp.php?mode=register) to search product forums and post questions.

## Discrepancies in the Documentation

All of this documentation can be modified by you! Please help us make it better.

* The documentation files for these pages are contained in the [`docs` folder](https://github.com/sparkfun/SparkFun_Indoor_Air_Quality_Sensor-SCD41-SEN55/tree/main/docs) of the [SparkFun SparkFun Air Quality Combo](https://github.com/sparkfun/SparkFun_Indoor_Air_Quality_Sensor-SCD41-SEN55) repository.

### Spot something wrong?
If a section of the documentation is incorrect, please [open an issue](https://github.com/sparkfun/SparkFun_Indoor_Air_Quality_Sensor-SCD41-SEN55/issues) and let us know.

### Do you have a suggested correction?
1. With a GitHub account, fork this repo
2. Add your correction(s) or improvement(s) to the markdown file(s)
3. File a pull request with your changes, and enjoy making the ~~words~~ ~~worlds~~ world a better place.
	* Once received, the documentation specialist will automatically be notified.
	* We will review your suggested improvement(s) to make sure they are correct and fit within our documentation standards.

## Problems in the Hardware Design

All of our designs are open-source! Please help us make it better.

* Our board design files are contained in the [`Hardware` folder](https://github.com/sparkfun/SparkFun_Indoor_Air_Quality_Sensor-SCD41-SEN55/tree/main/Hardware) of the [SparkFun SparkFun Air Quality Combo](https://github.com/sparkfun/SparkFun_Indoor_Air_Quality_Sensor-SCD41-SEN55) repository.

### Does something not make sense?
If part of the design is confusing, please [open an issue](https://github.com/sparkfun/SparkFun_Indoor_Air_Quality_Sensor-SCD41-SEN55/issues) and let us know.

### Did we forget to include an important function of the board?
* Please keep in mind that we may intentionally exclude certain functions of the board to meet our product design requirements. *(For example, our Qwiic Micro boards are intended to fit on a small board layout and only use I<sup>2</sup>C communication; therefore, we may not have the SPI and interrupt pins available for users.)*
* If part of the board's functionality is missing, please [open an issue](https://github.com/sparkfun/SparkFun_Indoor_Air_Quality_Sensor-SCD41-SEN55/issues) and file a feature request.

### Do you wish to contribute directly to improving the board design?
1. With a GitHub account, Fork this repo
2. Add your design improvement(s)
3. File a pull request with your changes, and enjoy making the ~~words~~ ~~worlds~~ world a better place.
	* Once received, the engineer in charge of the original design will automatically be notified.
	* We will review your suggested improvement(s), if they are within our board design standards and meet our product design requirements, we will flag these changes for our next board revision. *(Please note, that even if your suggestion is accepted, these changes may not be immediate. We may have to cycle through our current product inventory first.)*

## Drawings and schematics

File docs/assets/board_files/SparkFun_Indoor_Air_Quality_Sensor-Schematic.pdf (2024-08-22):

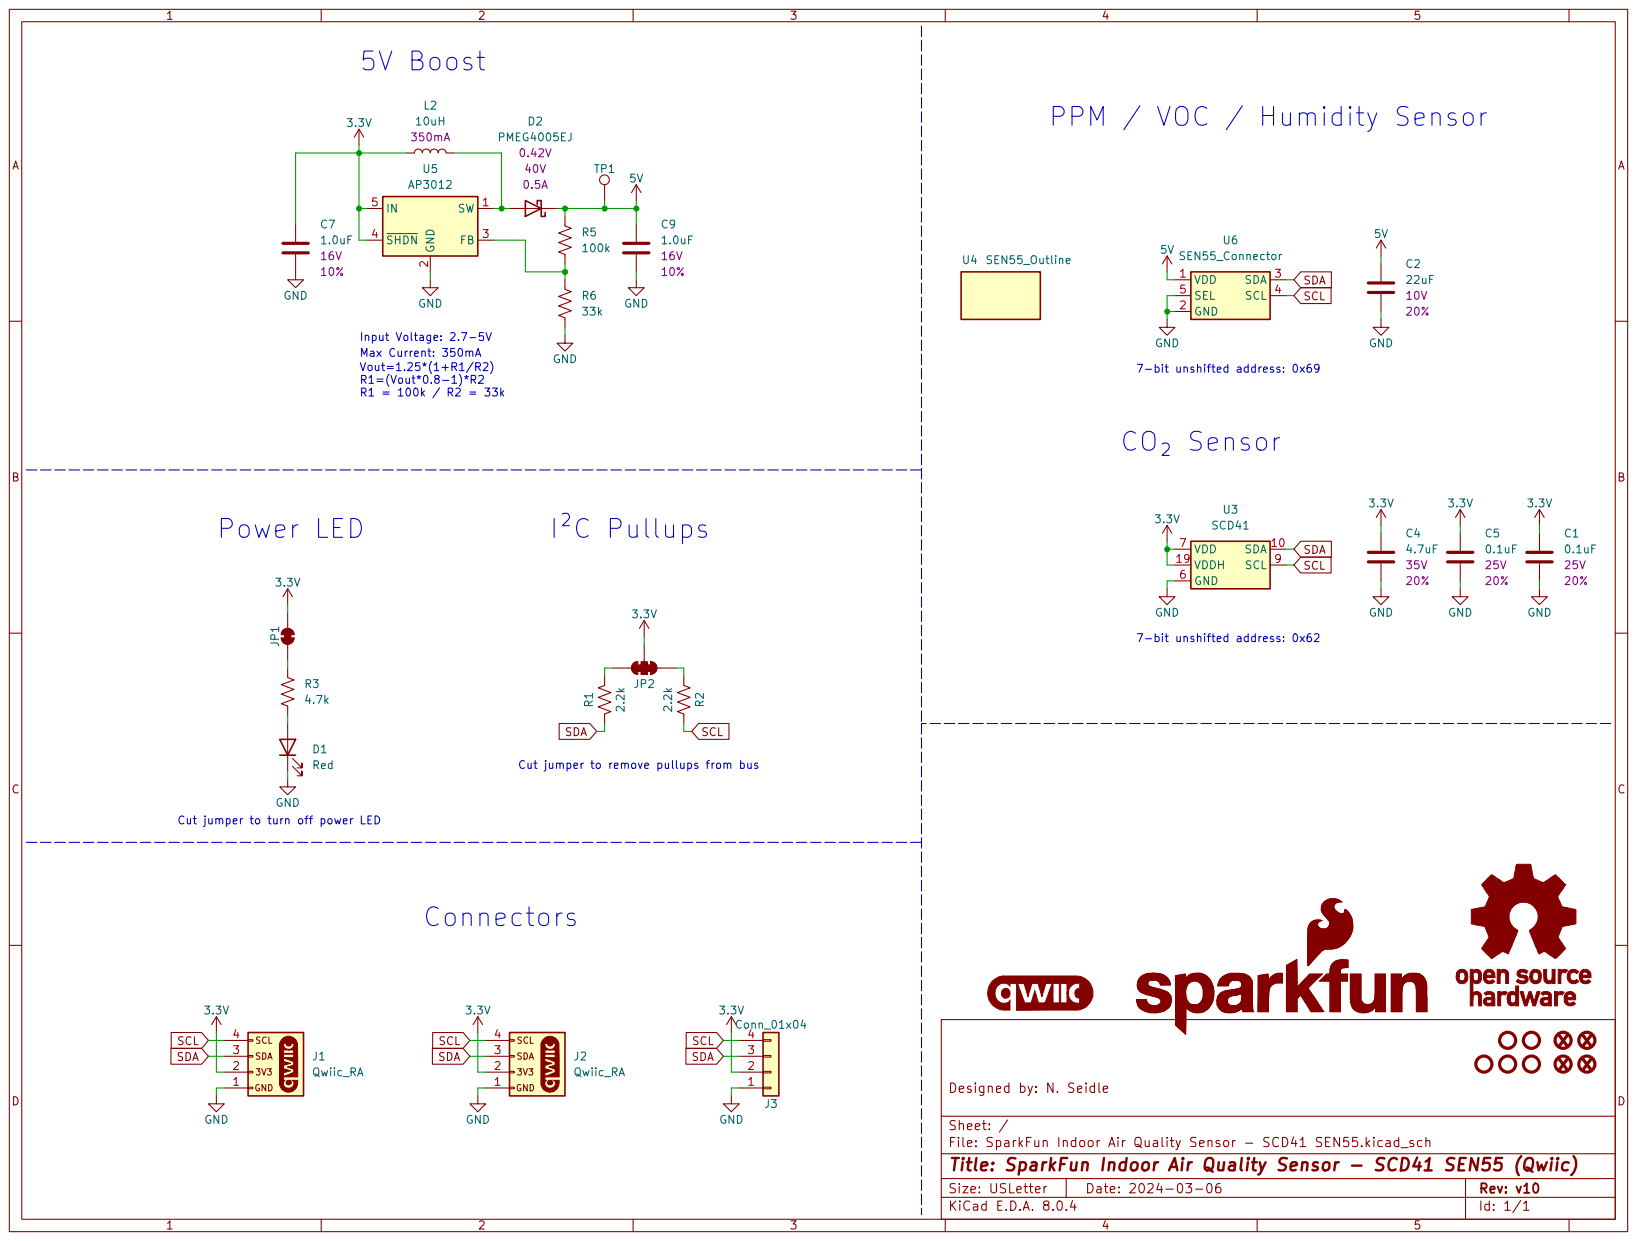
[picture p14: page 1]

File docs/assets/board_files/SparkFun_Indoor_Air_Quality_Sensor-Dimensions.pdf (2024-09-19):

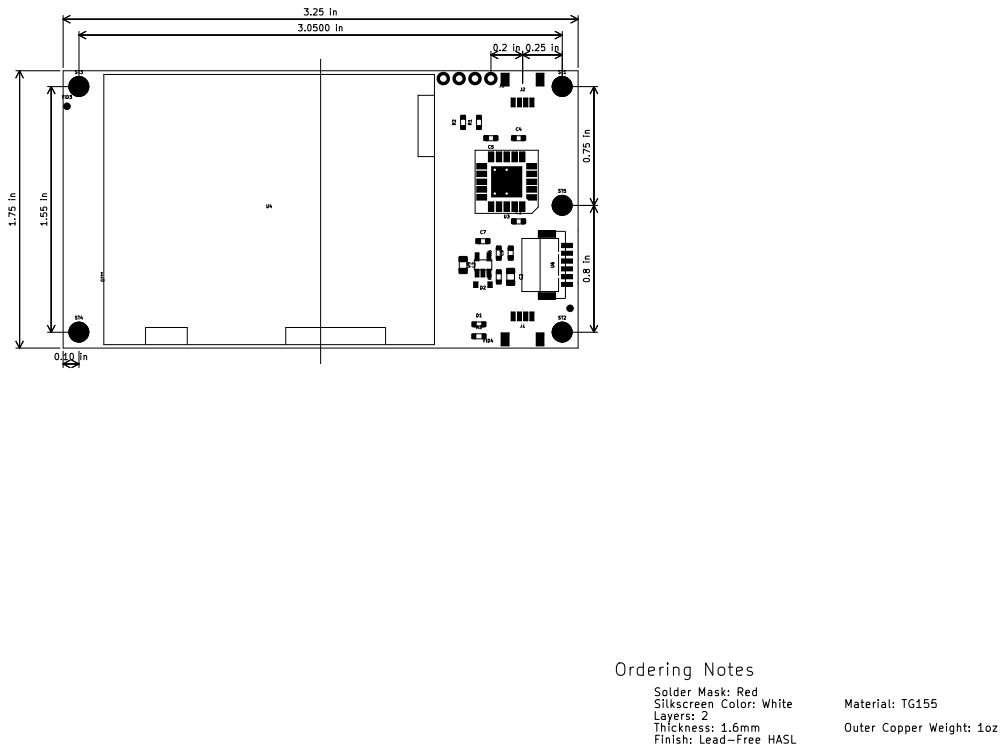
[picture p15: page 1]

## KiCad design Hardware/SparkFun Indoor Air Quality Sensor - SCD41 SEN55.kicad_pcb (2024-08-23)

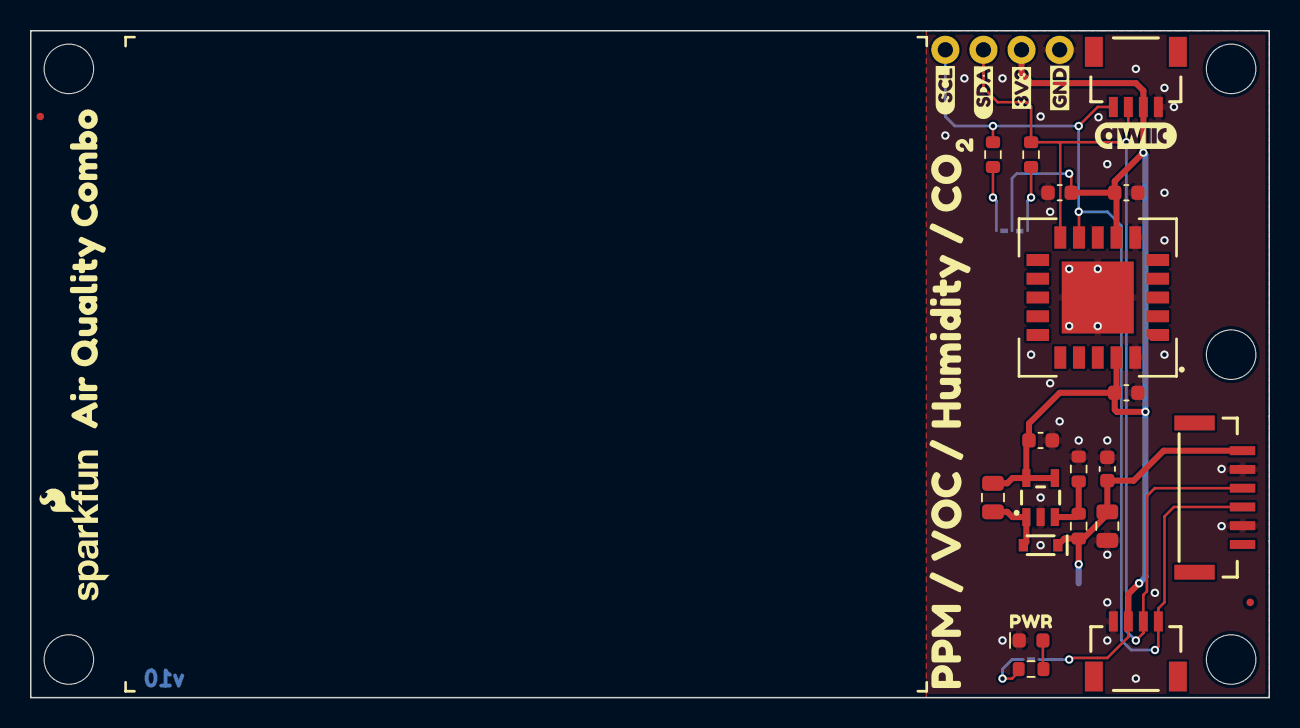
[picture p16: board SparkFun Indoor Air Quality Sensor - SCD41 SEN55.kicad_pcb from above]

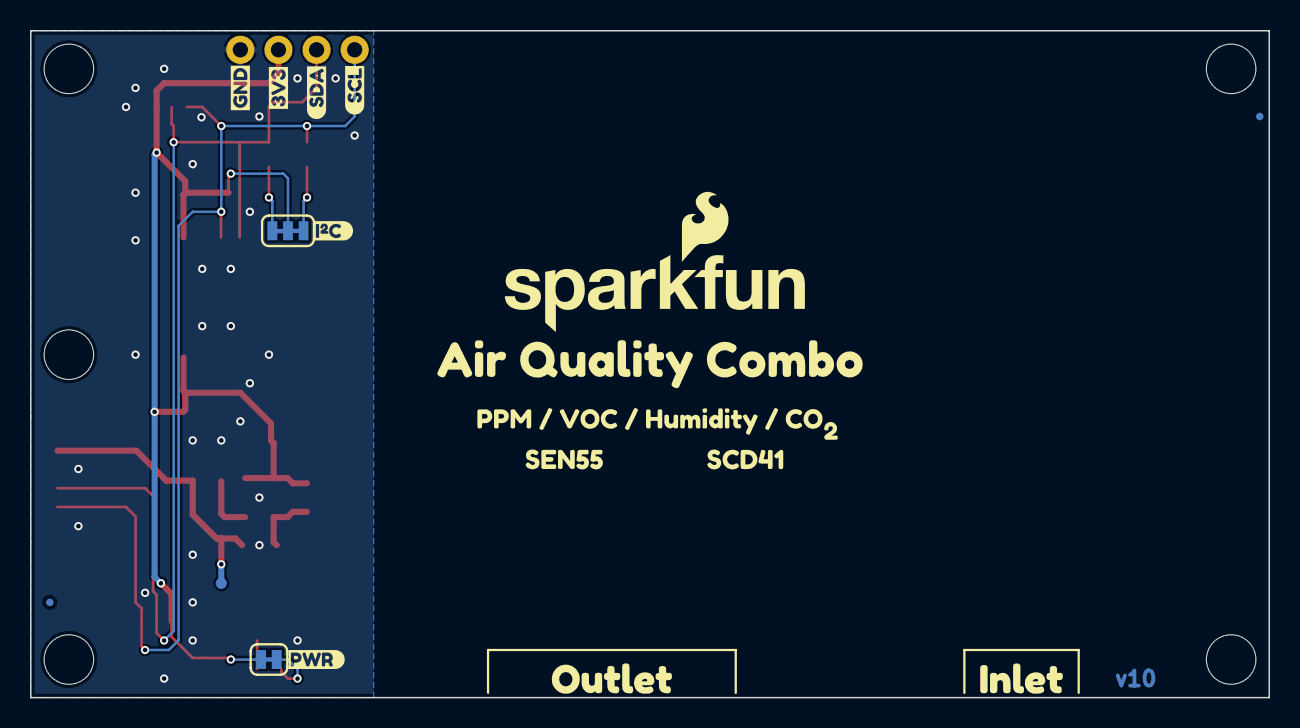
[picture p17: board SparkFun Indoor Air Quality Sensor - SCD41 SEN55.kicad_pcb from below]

Board: 2 copper layers, 82.5 x 44.5 mm, 55 parts (18 on the bottom side), 11 nets.

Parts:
C1, C5: 0.1uF; C_0603_1608Metric
C2: 22uF; C_0805_2012Metric
C4: 4.7uF; C_0603_1608Metric
C7, C9: 1.0uF; C_0603_1608Metric
D1: Red; LED_0603_1608Metric_Red
D2: PMEG4005EJ; SOD-323
FID1, FID2, FID3, FID4: Fiducial_0.5mm; Fiducial_0.5mm_Mask1mm
G4: OSHW_Logo; Creative_Commons_License
J1, J2: Qwiic_RA; JST_SMD_1.0mm-4_RA
J3: Conn_01x04; 1x04
JP1: Jumper_2_NC_Trace
JP2: Jumper_3_NC-2_Trace
L2: 10uH; C_0805_2012Metric
R1, R2: 2.2k; R_0603_1608Metric
R3: 4.7k; R_0603_1608Metric
R5: 100k; R_0603_1608Metric
R6: 33k; R_0603_1608Metric
ST1, ST2, ST3, ST4, ST5: Standoff
TP1: 0.75mm; TestPoint-0.75mm
U3: SCD41; SCD4x
U4: SEN55_Outline; SEN5x_Outline
U5: AP3012; SOT23-5
U6: SEN55_Connector; JST_SMD_1.25mm-6_Locking
kibuzzard-65A8A6F0: G***; kibuzzard-65A8A6F0
kibuzzard-65A8A8B4: G***; kibuzzard-65A8A8B4
kibuzzard-65A8A70D: G***; kibuzzard-65A8A70D
kibuzzard-65A8A702: G***; kibuzzard-65A8A702
kibuzzard-65A8A717: G***; kibuzzard-65A8A717
kibuzzard-65A8AE5A: G***; kibuzzard-65A8AE5A
kibuzzard-65A8AE51: G***; kibuzzard-65A8AE51
kibuzzard-65A8AE62: G***; kibuzzard-65A8AE62
kibuzzard-65A8AEA5: G***; kibuzzard-65A8AEA5
kibuzzard-65A8AED7: G***; kibuzzard-65A8AED7
kibuzzard-65A8AFF1: G***; kibuzzard-65A8AFF1
kibuzzard-65A8AFFA: G***; kibuzzard-65A8AFFA
kibuzzard-65A8B05B: G***; kibuzzard-65A8B05B
kibuzzard-65A8B028: G***; kibuzzard-65A8B028
kibuzzard-65A8B037: G***; kibuzzard-65A8B037
kibuzzard-65A75D7A, kibuzzard-65A75D7A#2: G***; kibuzzard-65A75D7A
kibuzzard-65A7583B: G***; kibuzzard-65A7583B
kibuzzard-65A75820: G***; kibuzzard-65A75820
kibuzzard-65CFEE26: G***; kibuzzard-65CFEE26
kibuzzard-65F20621: G***; kibuzzard-65F20621

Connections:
3.3V: C1.1, C4.1, C5.1, C7.1, J1.2, J2.2, J3.2, JP1.2 (B), JP2.2 (C), L2.1, U3.7 (VDD), U3.19 (VDDH), U5.4 (~SHDN), U5.5 (IN)
5V: C2.1, C9.1, D2.C, R5.1, TP1.1, U6.1 (VDD)
GND: C1.2, C2.2, C4.2, C5.2, C7.2, C9.2, D1.1 (K), J1.1, J2.1, J3.1, R6.2, U3.6 (GND), U3.20 (GND), U3.21 (GND), U5.2 (GND), U6.2 (GND), U6.5 (SEL)
unnamed: D1.2 (A), R3.2
unnamed: JP1.1 (A), R3.1
unnamed: JP2.1 (A), R2.1
unnamed: JP2.3 (B), R1.1
unnamed: R5.2, R6.1, U5.3 (FB)
unnamed: D2.A, L2.2, U5.1 (SW)
SCL: J1.4, J2.4, J3.4, R2.2, U3.9 (SCL), U6.4 (SCL)
SDA: J1.3, J2.3, J3.3, R1.2, U3.10 (SDA), U6.3 (SDA)

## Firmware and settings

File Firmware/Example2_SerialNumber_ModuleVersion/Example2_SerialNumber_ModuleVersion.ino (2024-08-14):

/*
  Reading SEN55 and SCD41 Dual Sensor Breakout
  By: Nathan Seidle
  SparkFun Electronics
  Date: August 14, 2024
  License: MIT. Please see LICENSE.md for more information.

  This example shows how to read the full set of sensor readings 
  from the Sensirion air particle/VOC/Humidty sensor (SEN55) and the CO2 sensor (SCD41).
  Particle readings are output once per second, CO2 is output every five seconds.
  Written primarily for ESP32 based boards but should work on others.

  This example contains additional output (serial number and module version).

  This example is a combination of the examples written by SparkFun and Sensirion:
  https://github.com/sparkfun/SparkFun_SCD4x_Arduino_Library
  https://github.com/Sensirion/arduino-i2c-sen5x

  Feel like supporting open source hardware?
  Buy a board from SparkFun!
  SparkFun Indoor Air Quality Sensor - SCD41 SEN55 (Qwiic) (SEN-25200) https://www.sparkfun.com/products/25200

  Hardware Connections:
  Plug a Qwiic cable into the board an ESP32 based board such as the SparkFun IoT RedBoard: https://www.sparkfun.com/products/19177
  If you don't have a platform with a Qwiic connection use the SparkFun Qwiic Breadboard Jumper (https://www.sparkfun.com/products/17912)
  Open the serial monitor at 115200 baud to see the output
*/

// The used commands use up to 48 bytes. On some Arduino's the default buffer
// space is not large enough
#define MAXBUF_REQUIREMENT 48

#if (defined(I2C_BUFFER_LENGTH) &&                 \
     (I2C_BUFFER_LENGTH >= MAXBUF_REQUIREMENT)) || \
    (defined(BUFFER_LENGTH) && BUFFER_LENGTH >= MAXBUF_REQUIREMENT)
#define USE_PRODUCT_INFO
#endif

#include <SensirionCore.h>// Click here to get the library: http://librarymanager/All#Sensirion_Core_Base
#include <SensirionI2CSen5x.h>// Click here to get the library: http://librarymanager/All#Sensirion_Sen5x
SensirionI2CSen5x sen5x;

#include "SparkFun_SCD4x_Arduino_Library.h" //Click here to get the library: http://librarymanager/All#SparkFun_SCD4x
SCD4x scd4x;

// Measurement Variables
float pm1p0;
float pm2p5;
float pm4p0;
float pm10p0;
float sen5xHumidity;
float ambientTemperature;
float vocIndex;
float noxIndex;

void setup()
{
  Serial.begin(115200);
  delay(250);

  Wire.begin();

  sen5x.begin(Wire);

  uint16_t error;
  char errorMessage[256];
  error = sen5x.deviceReset();
  if (error) {
    Serial.print("Error trying to execute deviceReset(): ");
    errorToString(error, errorMessage, 256);
    Serial.println(errorMessage);
  }

  // Print SEN55 module information if i2c buffers are large enough
#ifdef USE_PRODUCT_INFO
  printSerialNumber();
  printModuleVersions();
#endif

  // set a temperature offset in degrees celsius
  // Note: supported by SEN54 and SEN55 sensors
  // By default, the temperature and humidity outputs from the sensor
  // are compensated for the modules self-heating. If the module is
  // designed into a device, the temperature compensation might need
  // to be adapted to incorporate the change in thermal coupling and
  // self-heating of other device components.
  //
  // A guide to achieve optimal performance, including references
  // to mechanical design-in examples can be found in the app note
  // “SEN5x – Temperature Compensation Instruction” at www.sensirion.com.
  // Please refer to those application notes for further information
  // on the advanced compensation settings used
  // in `setTemperatureOffsetParameters`, `setWarmStartParameter` and
  // `setRhtAccelerationMode`.
  //
  // Adjust tempOffset to account for additional temperature offsets
  // exceeding the SEN module's self heating.
  float tempOffset = 0.0;
  error = sen5x.setTemperatureOffsetSimple(tempOffset);
  if (error) {
    Serial.print("Error trying to execute setTemperatureOffsetSimple(): ");
    errorToString(error, errorMessage, 256);
    Serial.println(errorMessage);
  } else {
    Serial.print("Temperature Offset set to ");
    Serial.print(tempOffset);
    Serial.println(" deg. Celsius (SEN54/SEN55 only)");
  }

  // Start Measurement
  error = sen5x.startMeasurement();
  if (error) {
    Serial.print("Error trying to execute startMeasurement(): ");
    errorToString(error, errorMessage, 256);
    Serial.println(errorMessage);
  }

  //Start SCD4x CO2 measurements
  if (scd4x.begin() == false)
  {
    Serial.println(F("SCD4x not detected. Please check wiring. Freezing..."));
    while (true);
  }

  //The SCD4x has data ready every five seconds
}

void loop()
{
  uint16_t error;
  char errorMessage[256];

  error = sen5x.readMeasuredValues(
            pm1p0, pm2p5, pm4p0,
            pm10p0, sen5xHumidity, ambientTemperature, vocIndex,
            noxIndex);

  if (error) {
    Serial.print("Error trying to execute readMeasuredValues(): ");
    errorToString(error, errorMessage, 256);
    Serial.println(errorMessage);
  } else {
    Serial.print("SEN5x ");

    Serial.print("Pm1p0:");
    Serial.print(pm1p0);
    Serial.print(" ");
    Serial.print("Pm2p5:");
    Serial.print(pm2p5);
    Serial.print(" ");
    Serial.print("Pm4p0:");
    Serial.print(pm4p0);
    Serial.print(" ");
    Serial.print("Pm10p0:");
    Serial.print(pm10p0);
    Serial.print(" ");
    Serial.print("Humidity:");
    if (isnan(sen5xHumidity)) {
      Serial.print("n/a");
    } else {
      Serial.print(sen5xHumidity);
    }
    Serial.print(" ");
    Serial.print("Temp:");
    if (isnan(ambientTemperature)) {
      Serial.print("n/a");
    } else {
      Serial.print(ambientTemperature);
    }
    Serial.print(" ");
    Serial.print("VocIndex:");
    if (isnan(vocIndex)) {
      Serial.print("n/a");
    } else {
      Serial.print(vocIndex);
    }
    Serial.print(" ");
    Serial.print("NoxIndex:");
    if (isnan(noxIndex)) {
      Serial.println("n/a");
    } else {
      Serial.println(noxIndex);
    }
  }

  if (scd4x.readMeasurement()) // readMeasurement will return true when fresh data is available
  {
    Serial.print("SCD4x ");

    Serial.print("CO2(ppm):");
    Serial.print(scd4x.getCO2());

    Serial.print(" Temperature(C):");
    Serial.print(scd4x.getTemperature(), 1);

    Serial.print(" Humidity(%RH):");
    Serial.print(scd4x.getHumidity(), 1);

    Serial.println();
  }

  delay(1000);
}

void printModuleVersions()
{
  uint16_t error;
  char errorMessage[256];

  unsigned char productName[32];
  uint8_t productNameSize = 32;

  error = sen5x.getProductName(productName, productNameSize);

  if (error) {
    Serial.print("Error trying to execute getProductName(): ");
    errorToString(error, errorMessage, 256);
    Serial.println(errorMessage);
  } else {
    Serial.print("ProductName:");
    Serial.println((char*)productName);
  }

  uint8_t firmwareMajor;
  uint8_t firmwareMinor;
  bool firmwareDebug;
  uint8_t hardwareMajor;
  uint8_t hardwareMinor;
  uint8_t protocolMajor;
  uint8_t protocolMinor;

  error = sen5x.getVersion(firmwareMajor, firmwareMinor, firmwareDebug,
                           hardwareMajor, hardwareMinor, protocolMajor,
                           protocolMinor);
  if (error) {
    Serial.print("Error trying to execute getVersion(): ");
    errorToString(error, errorMessage, 256);
    Serial.println(errorMessage);
  } else {
    Serial.print("Firmware: ");
    Serial.print(firmwareMajor);
    Serial.print(".");
    Serial.print(firmwareMinor);
    Serial.print(", ");

    Serial.print("Hardware: ");
    Serial.print(hardwareMajor);
    Serial.print(".");
    Serial.println(hardwareMinor);
  }
}

void printSerialNumber() {
  uint16_t error;
  char errorMessage[256];
  unsigned char serialNumber[32];
  uint8_t serialNumberSize = 32;

  error = sen5x.getSerialNumber(serialNumber, serialNumberSize);
  if (error) {
    Serial.print("Error trying to execute getSerialNumber(): ");
    errorToString(error, errorMessage, 256);
    Serial.println(errorMessage);
  } else {
    Serial.print("SerialNumber:");
    Serial.println((char*)serialNumber);
  }
}

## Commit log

2024-02-16 Move connector to avoid cable over silk
    [SparkFun_AirQuality_Combo.kicad_pcb]
2024-02-20 Remove proto files
    [SparkFun_AirQuality_Combo.GBL, SparkFun_AirQuality_Combo.GBO, SparkFun_AirQuality_Combo.GBP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]
2024-02-20 Add schematic. Fix ignore.
    [SparkFun_AirQuality_Combo.kicad_sch]
2024-03-06 Pre design review changes
    [SparkFun_AirQuality_Combo.kicad_pcb, SparkFun_AirQuality_Combo.kicad_sch]
2024-03-06 Pre design review updates
    [SparkFun_AirQuality_Combo.kicad_sch]
2024-03-13 Add PTH at 0.8"
    [SparkFun_AirQuality_Combo.kicad_pcb, SparkFun_AirQuality_Combo.kicad_sch]
2024-03-13 Add panel files
    [SparkFun_AirQuality_Combo_panelized.GBL, SparkFun_AirQuality_Combo_panelized.GBO, SparkFun_AirQuality_Combo_panelized.GBP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]
2024-03-13 File rename
    [SparkFun Indoor Air Quality Sensor - SCD41 SEN55.kicad_pcb, SparkFun Indoor Air Quality Sensor - SCD41 SEN55.kicad_sch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]
2024-08-05 Fix PROD_ID on SEN55 connector and module.
    [SparkFun Indoor Air Quality Sensor - SCD41 SEN55.kicad_pcb, SparkFun Indoor Air Quality Sensor - SCD41 SEN55.kicad_sch]
2024-08-23 Update 3D models
    [SparkFun Indoor Air Quality Sensor - SCD41 SEN55.kicad_pcb, SparkFun Indoor Air Quality Sensor - SCD41 SEN55.kicad_sch]
2024-10-01 Update software_setup.md
    Fixed formatting error for library download buttons.

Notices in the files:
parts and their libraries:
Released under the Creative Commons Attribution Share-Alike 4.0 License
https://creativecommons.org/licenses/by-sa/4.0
